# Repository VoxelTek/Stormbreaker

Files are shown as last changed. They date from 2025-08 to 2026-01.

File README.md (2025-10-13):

# Stormbreaker
### ~~A ripoff of YveltalGriffin's Mjolnir~~ 
### A companion board for [Thundervolt](https://github.com/mackieks/thundervolt)

Stormbreaker PCB front




## What is this?
Stormbreaker is a multifunction circuit board intended to be used alongside [Thundervolt](https://github.com/mackieks/thundervolt) in Wii portables. It handles battery charging and monitoring, power switching, storage interfacing, and a bit more. See the full list of features here.

## Why did I design this?
Thundervolt, while incredible, does not provide any battery management capability, nor does it provide any way for a user to toggle power to the system outside of disconnecting power from Thundervolt itself. As such, following the completion of Thundervolt, its creator YveltalGriffin began work on a companion board, named "Mjolnir". Mjolnir would handle everything from battery management to storage to fan control and more, and would integrate seamlessly with Thundervolt. However, development on Mjolnir has been temporarily halted, which pushed me to make a companion board myself. Hence, Stormbreaker was born.

## Where did the name come from?
In Norse mythology, Thor is the God of Thunder, and is often seen alongside his hammer, Mjolnir. In the Marvel Cinematic Universe, Thor lost Mjolnir, and instead forged an axe called Stormbreaker. 

As such, it seemed fitting to name this board, born from the absense of Mjolnir, "Stormbreaker".
###### Disclaimer: this board is not capable of summoning the Bifrost. PRs are welcome.

## What can this board do?
Functionality is largely split between the 4 ICs.
#### U1 - BQ25895
- Battery charging
  - Fast charging capability
  - Play-and-charge capability
- Battery voltage monitoring
  - Used to determine approximate remaining battery capacity (i.e. "percent")
- Shipping mode
#### U2 - GL835
- microSD to USB 2.0 adapter
- Supports hot-swaping microSD cards
#### U3 - ATtiny1616
- Initialises ICs
- Monitors system
  - Shuts off console in event of over-temp
  - Engages shipping mode when requested
  - Responds to errors from U1
- Powers on/off console after button press
  - Has safe shutdown capability
- Drives Neopixel LED (WS2812 or compatible)
- Controls fan speed using PWM
- Communicates with Wii over I2C
  - RVLoader fork allows various adjustments, including charge currents and charge voltage
#### U4 - HUSB238A
- PD sink controller
- Uses USB-C PD to request higher voltages (up to 12V) to allow for faster charging with lower current draw

GIF of rotating Stormbreaker PCB

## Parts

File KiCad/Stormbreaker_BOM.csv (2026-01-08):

Id | Designator | Footprint | Quantity | Designation | Supplier and ref
3 | C13 | C_0603_1608Metric | 1 | 0.1uF
5 | C5,C7,C6 | C_0402_1005Metric | 3 | 22uF
6 | U1 | Texas_RTW_WQFN-24-1EP_4x4mm_P0.5mm_EP2.7x2.7mm_ThermalVias | 1 | BQ25895RTW
7 | R9,R10,R11 | R_0402_1005Metric | 3 | 10k
8 | U3 | VQFN-20-1EP_3x3mm_P0.4mm_EP1.7x1.7mm | 1 | ATtiny1616-M
9 | C4,C9 | C_0402_1005Metric | 2 | 4.7uF
11 | L1 | L_PCMB053T | 1 | 3.3uH
15 | C12,C15,C8 | C_0402_1005Metric | 3 | 1μF
16 | R1 | R_0402_1005Metric | 1 | 260
17 | U2 | HVQFN-24-1EP_4x4mm_P0.5mm_EP2.5x2.5mm | 1 | ~
18 | C2,C1,C14,C16 | C_0603_1608Metric | 4 | 10uF
20 | J2 | USB_C_Receptacle_GCT_USB4105-xx-A_16P_TopMnt_Horizontal | 1 | USB_C_Receptacle_USB2.0_14P
21 | BT2 | JST_PH_B2B-PH-K_1x02_P2.00mm_Vertical | 1 | Battery_Cell
23 | Q2 | SOT-523 | 1 | NMOS
24 | Q1 | Vishay_PowerPAK_1212-8_Single | 1 | PMOS
25 | J1 | microSD_HC_Hirose_DM3D-SF | 1 | Micro_SD_Card_Det1
28 | SW1 | SW_TL3330AF260QG | 1 | SW_Push
29 | R2 | R_0402_1005Metric | 1 | 30.1k
30 | R7,R5 | R_0402_1005Metric | 2 | 1k
32 | R6 | R_0402_1005Metric | 1 | 900k
34 | R8 | R_0402_1005Metric | 1 | 100k
36 | R3 | R_0402_1005Metric | 1 | 5.23k
37 | U4 | QFN-16-1EP_3x3mm_P0.5mm_EP1.7x1.7mm_ThermalVias | 1 | HUSB238A
39 | C3 | C_0402_1005Metric | 1 | 47nF

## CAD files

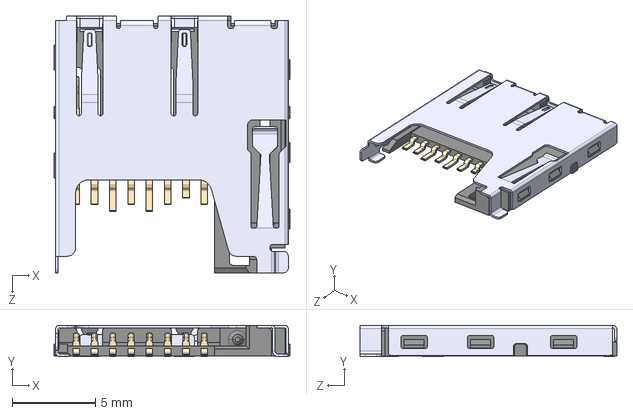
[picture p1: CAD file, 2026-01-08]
KiCad/3D/MEM2061-01-188-00-A.STEP
14.2 x 1.88 x 15.4 mm

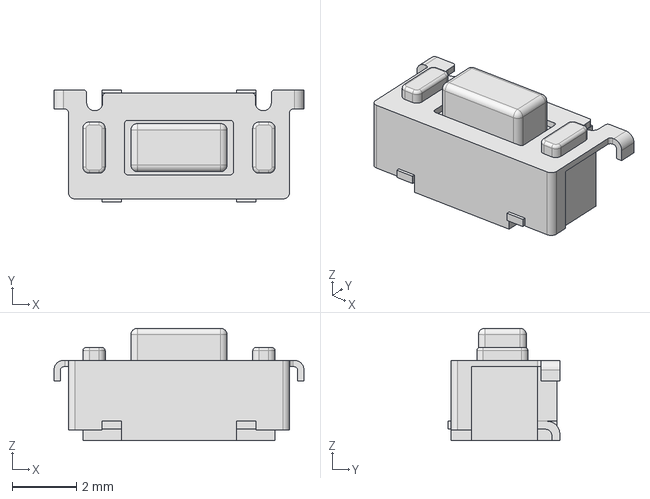
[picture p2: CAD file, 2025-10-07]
KiCad/3D/TL3330AFxxxQG.stp
7.80 x 3.50 x 3.51 mm

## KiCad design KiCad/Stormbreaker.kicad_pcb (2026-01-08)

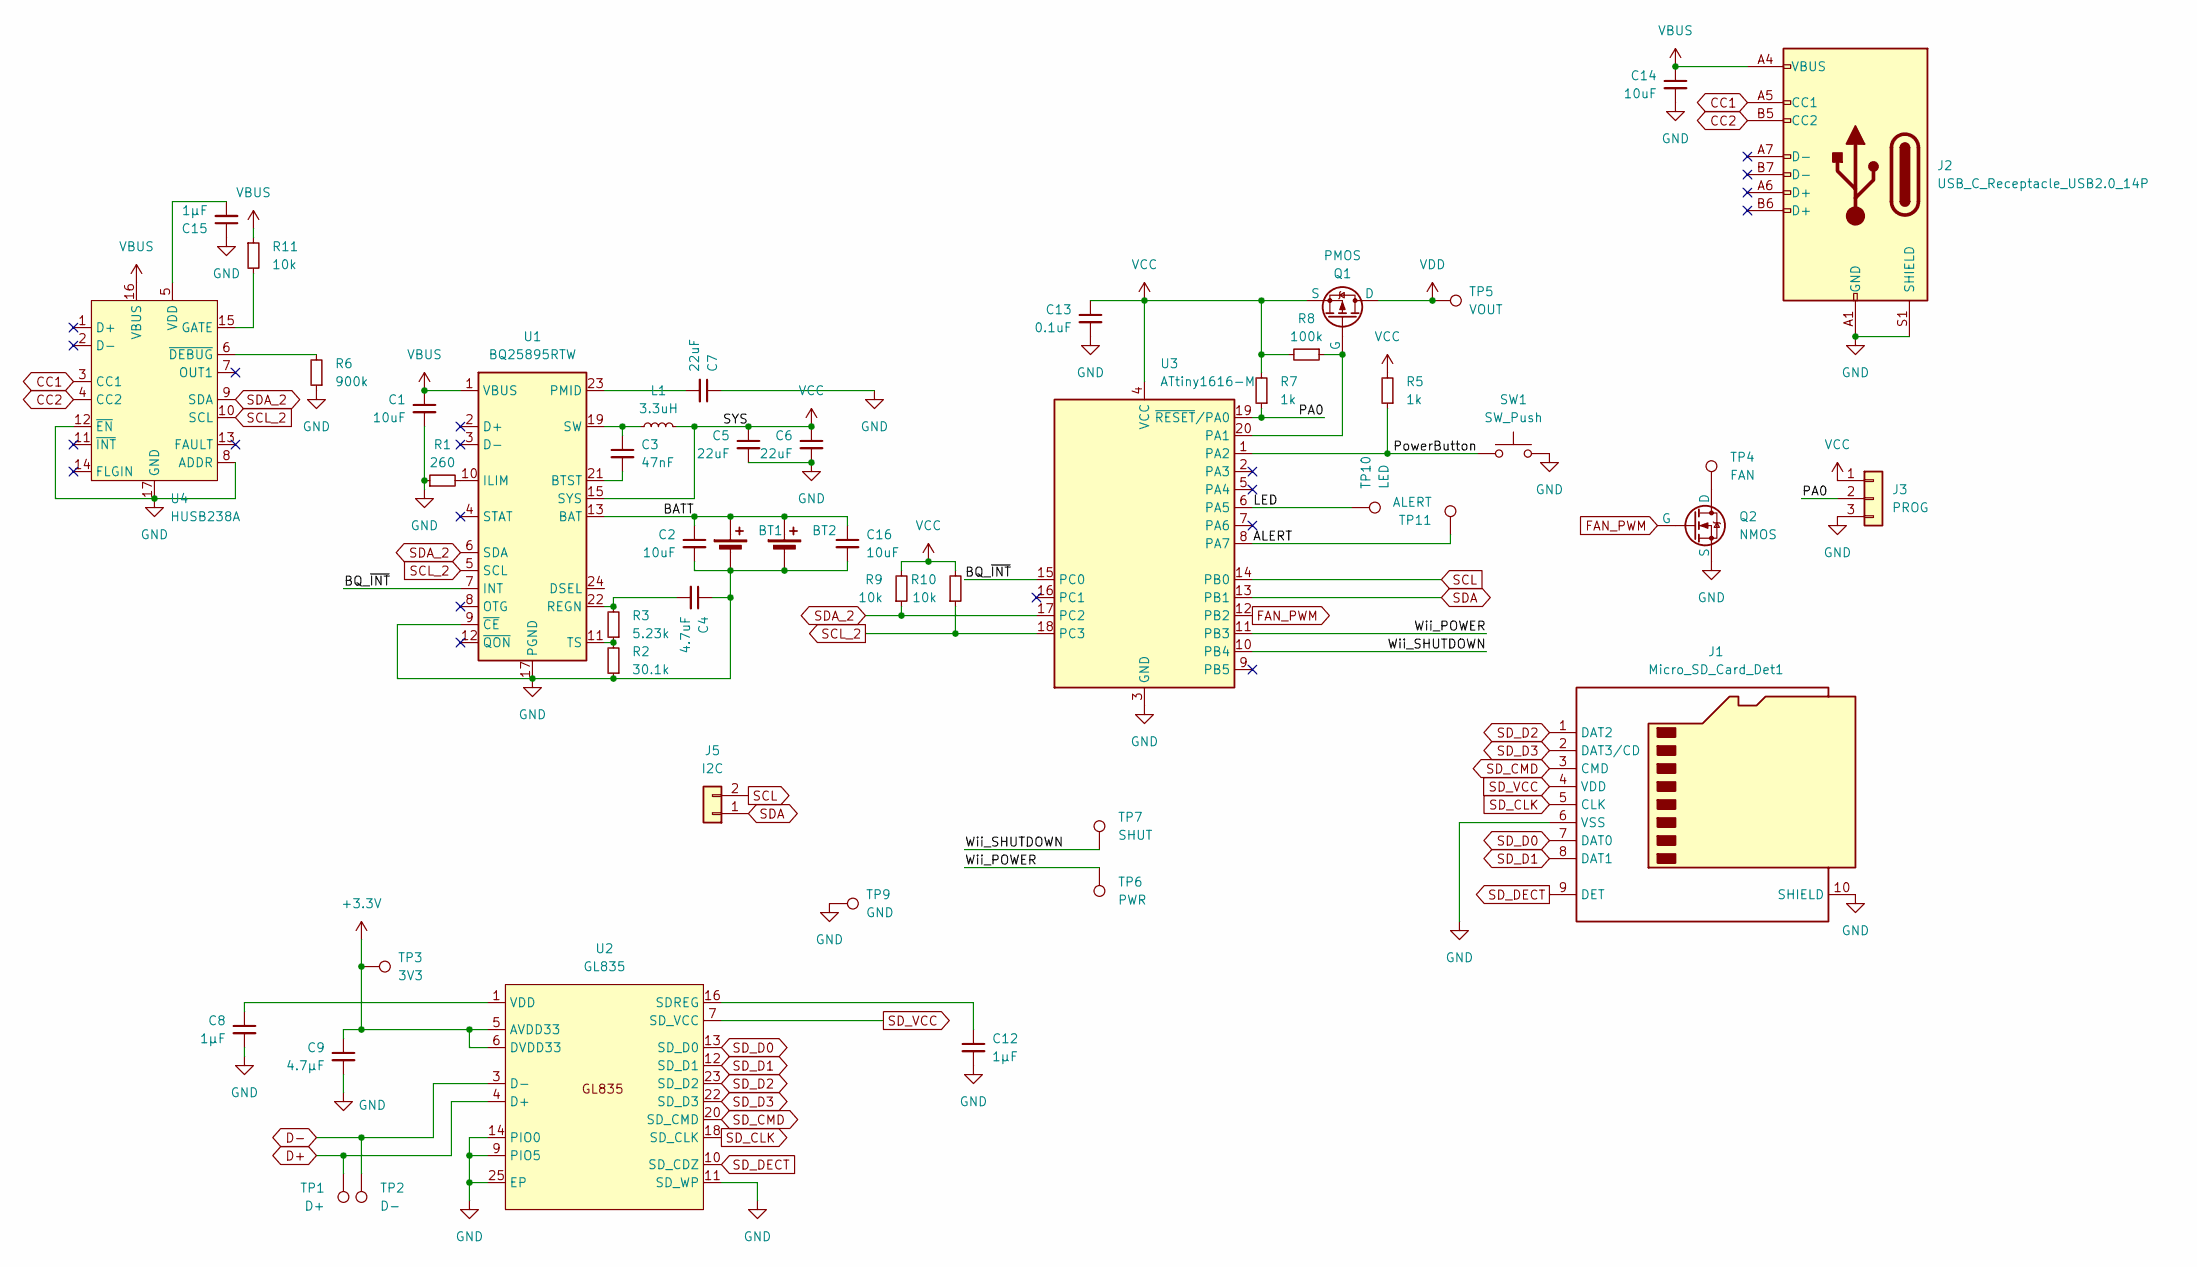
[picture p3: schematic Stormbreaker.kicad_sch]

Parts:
BT1: Battery_Cell; PinSocket_1x02_P1.27mm_Vertical
BT2: Battery_Cell; JST_PH_B2B-PH-K_1x02_P2.00mm_Vertical
C1, C2, C14, C16: 10uF; C_0603_1608Metric
C3: 47nF; C_0402_1005Metric
C4: 4.7uF; C_0402_1005Metric
C5, C6, C7: 22uF; C_0402_1005Metric
C8, C12, C15: 1μF; C_0402_1005Metric
C9: 4.7μF; C_0402_1005Metric
C13: 0.1uF; C_0603_1608Metric
J1: Micro_SD_Card_Det1; microSD_HC_Hirose_DM3D-SF
J2: USB_C_Receptacle_USB2.0_14P; USB_C_Receptacle_GCT_USB4105-xx-A_16P_TopMnt_Horizontal
J3: PROG; UPDI Pads
J5: I2C; PinSocket_1x02_P1.00mm_Vertical
L1: 3.3uH; L_PCMB053T
Q1: PMOS; Vishay_PowerPAK_1212-8_Single; Mouser au.mouser.com/ProductDetail/Vishay-Semi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
Q2: NMOS; SOT-523
R1: 260; R_0402_1005Metric
R2: 30.1k; R_0402_1005Metric
R3: 5.23k; R_0402_1005Metric
R5, R7: 1k; R_0402_1005Metric
R6: 900k; R_0402_1005Metric
R8: 100k; R_0402_1005Metric
R9, R10, R11: 10k; R_0402_1005Metric
SW1: SW_Push; SW_TL3330AF260QG
TP1: D+; TestPoint_Pad_D1.0mm_Small
TP2: D-; TestPoint_Pad_D1.0mm_Small
TP3: 3V3; TestPoint_Pad_D1.5mm
TP4: FAN; TestPoint_Pad_D1.0mm_Small
TP5: VOUT; TestPoint_Pad_D2.5mm
TP6: PWR; TestPoint_Pad_D1.0mm_Small
TP7: SHUT; TestPoint_Pad_D1.0mm_Small
TP9: GND; TestPoint_Pad_D2.5mm
TP10: LED; TestPoint_Pad_D1.0mm_Small
TP11: ALERT; TestPoint_Pad_D1.0mm_Small
U1: BQ25895RTW; Texas_RTW_WQFN-24-1EP_4x4mm_P0.5mm_EP2.7x2.7mm_ThermalVias
U2: GL835; HVQFN-24-1EP_4x4mm_P0.5mm_EP2.5x2.5mm
U3: ATtiny1616-M; VQFN-20-1EP_3x3mm_P0.4mm_EP1.7x1.7mm
U4: HUSB238A; QFN-16-1EP_3x3mm_P0.5mm_EP1.7x1.7mm_ThermalVias

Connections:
+3.3V: C9.1, TP3.1, U2.5 (AVDD33), U2.6 (DVDD33)
/ALERT: TP11.1, U3.8 (PA7)
/BATT: BT1.1 (+), BT2.1 (+), C2.1, C16.1, U1.13 (BAT), U1.14 (BAT)
/BQ_~INT: U1.7 (INT), U3.15 (PC0)
/LED: TP10.1, U3.6 (PA5)
/PA0: J3.2, R7.1, U3.19 (~RESET/PA0)
/PowerButton: R5.1, SW1.1, U3.1 (PA2)
/Wii_POWER: TP6.1, U3.11 (PB3)
/Wii_SHUTDOWN: TP7.1, U3.10 (PB4)
CC1: J2.A5 (CC1), U4.3 (CC1)
CC2: J2.B5 (CC2), U4.4 (CC2)
D+: TP1.1, U2.4 (D+)
D-: TP2.1, U2.3 (D-)
FAN_PWM: Q2.1 (G), U3.12 (PB2)
GND: BT1.2 (-), BT2.2 (-), C1.2, C2.2, C4.1, C5.2, C6.2, C7.1, C8.2, C9.2, C12.2, C13.2, C14.2, C15.1, C16.2, J1.6 (VSS), J1.10 (SHIELD), J1.11 (SHIELD), J2.A1 (GND), J2.A12 (GND), J2.B1 (GND), J2.B12 (GND), J2.S1 (SHIELD), J3.3, Q2.2 (S), R1.1, R2.1, R6.1, SW1.2, SW1.MP, TP9.1, U1.9 (~CE), U1.17 (PGND), U1.18 (PGND), U1.25 (PGND), U2.9 (PIO5), U2.11 (SD_WP), U2.14 (PIO0), U2.25 (EP), U3.3 (GND), U3.21 (GND), U4.8 (ADDR), U4.12 (~EN), U4.17 (GND)
unnamed: C3.1, L1.1, U1.19 (SW), U1.20 (SW)
unnamed: Q1.4 (G), R8.1, U3.20 (PA1)
unnamed: Q2.3 (D), TP4.1
unnamed: C3.2, U1.21 (BTST)
unnamed: R1.2, U1.10 (ILIM)
unnamed: C7.2, U1.23 (PMID)
unnamed: C4.2, R3.2, U1.22 (REGN)
unnamed: R2.2, R3.1, U1.11 (TS)
unnamed: C12.1, U2.16 (SDREG)
unnamed: C8.1, U2.1 (VDD)
unnamed: R11.2, U4.15 (GATE)
unnamed: C15.2, U4.5 (VDD)
unnamed: R6.2, U4.6 (~DEBUG)
SCL: J5.2, U3.14 (PB0)
SCL_2: R10.1, U1.5 (SCL), U3.18 (PC3), U4.10 (SCL)
SDA: J5.1, U3.13 (PB1)
SDA_2: R9.1, U1.6 (SDA), U3.17 (PC2), U4.9 (SDA)
SD_CLK: J1.5 (CLK), U2.18 (SD_CLK)
SD_CMD: J1.3 (CMD), U2.20 (SD_CMD)
SD_D0: J1.7 (DAT0), U2.13 (SD_D0)
SD_D1: J1.8 (DAT1), U2.12 (SD_D1)
SD_D2: J1.1 (DAT2), U2.23 (SD_D2)
SD_D3: J1.2 (DAT3/CD), U2.22 (SD_D3)
SD_DECT: J1.9 (DET), U2.10 (SD_CDZ)
SD_VCC: J1.4 (VDD), U2.7 (SD_VCC)
VBUS: C1.1, C14.1, J2.A4 (VBUS), J2.A9 (VBUS), J2.B4 (VBUS), J2.B9 (VBUS), R11.1, U1.1 (VBUS), U4.16 (VBUS)
VCC: C5.1, C6.1, C13.1, J3.1, L1.2, Q1.1 (S), Q1.2 (S), Q1.3 (S), R5.2, R7.2, R8.2, R9.2, R10.2, U1.15 (SYS), U1.16 (SYS), U3.4 (VCC); also elsewhere on the board
VDD: Q1.5 (D), TP5.1

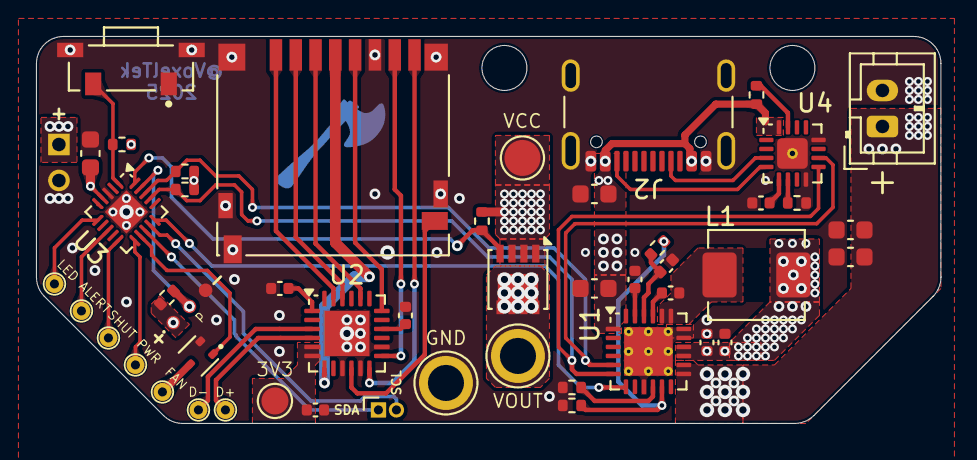
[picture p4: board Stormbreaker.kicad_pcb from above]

Board: 4 copper layers, 50.2 x 21.5 mm, 49 parts (0 on the bottom side), 43 nets.

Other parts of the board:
TP8: VCC; TestPoint_Pad_D2.0mm

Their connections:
VCC: TP8.1; also elsewhere on the board

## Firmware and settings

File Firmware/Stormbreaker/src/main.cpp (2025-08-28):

#include "main.h"

#include <avr/eeprom.h>
#include <avr/sleep.h>
#include <avr/interrupt.h>
#include <avr/io.h>
#include <avr/power.h>

#include <util/delay.h>

//#include <tinyNeoPixel.h>

#include "i2c_target.h"

#include "gpio.h"

#define STORM_I2C 0x50

#define ADDR_VER 0x00
#define ADDR_CHRGCURRENT 0x01
#define ADDR_PRECURRENT 0x02
#define ADDR_TERMCURRENT 0x03
#define ADDR_CHRGVOLTAGE 0x04
#define ADDR_FANSPEED 0x05

uint8_t ver = 0x01; // v0.1 (ver / 10)

//BBI2C bbi2c;

bool isPowered = false; // Is the Wii powered?
bool isCharging = false; // Is the BQ charging the batteries?

bool buttonTriggered = false; // Has the button been triggered?
bool triggeredSoftShutdown = false; // Did we trigger the soft shutdown?

bool isOverTemp = false;

uint8_t battCharge;
uint8_t battVolt = 0b1000101; //~3.7V
const uint8_t minBattVolt = 0b0010011; //~2.7V
uint8_t battVoltLevels[5] = {0b01011111, 0b1000101, 0b0100010, 0b0011000, 0b0010011}; // 4.2, 3.7, 3.0, 2.8, 2.7
uint8_t battChrgLevels[9] = {minBattVolt, 0x1c, 0x26, 0x30, 0x39, 0x43, 0x4c, 0x56, 0x5f};
uint8_t pwrErrorStatus = 0x00;
uint8_t chargeStatus = 0b00;
const uint8_t bqAddr = 0x6A;
uint8_t maxCurrent = 0x3F; // 3.25A
//byte chrgCurrent = 0b1000010; // 4224mA

/*
byte chrgCurrent = EEPROM.read(ADDR_CHRGCURRENT);
byte preCurrent = EEPROM.read(ADDR_PRECURRENT);
byte termCurrent = EEPROM.read(ADDR_TERMCURRENT);
byte chrgVoltage = EEPROM.read(ADDR_CHRGVOLTAGE);
*/

uint8_t chrgCurrent;
uint8_t preCurrent;
uint8_t termCurrent;
uint8_t chrgVoltage;
uint8_t fanSpeed;

const bool ilimEnabled = false;

//tinyNeoPixel pixels = tinyNeoPixel(NUMPIXELS, PIN_PA5, NEO_GRB);

/*
int I2CWriteRegister(BBI2C *pI2C, unsigned char iAddr, unsigned char reg, unsigned char value) {
    unsigned char buffer[2];
    buffer[0] = reg;   // Register address
    buffer[1] = value; // Data to write

    return I2CWrite(pI2C, iAddr, buffer, 2);
}
*/

void firstTimeCheck() {
  if (eeprom_read_byte(ADDR_VER) == 0) { // Check if there's no data in the EEPROM
    chrgCurrent = 0b1000010; // 4224mA
    preCurrent = 0b0001;
    termCurrent = 0b0011;
    chrgVoltage = 0b010111;
    fanSpeed = 0xFF;
    writeToEEPROM(); 
  }
  else {
    chrgCurrent = eeprom_read_byte(ADDR_CHRGCURRENT);
    preCurrent = eeprom_read_byte(ADDR_PRECURRENT);
    termCurrent = eeprom_read_byte(ADDR_TERMCURRENT);
    chrgVoltage = eeprom_read_byte(ADDR_CHRGVOLTAGE);
    fanSpeed = eeprom_read_byte(ADDR_FANSPEED);
  }
  eeprom_write_byte(ADDR_VER, ver);
}

int handle_register_read(uint8_t reg_addr, uint8_t *value) {
  /*
  if (numBytes == 0) return;

  byte reg = Wire.read();

  switch (reg) {
    case 0x00: // Get version
      requestedReg = &ver;
    break;

    case 0x02:
      applyChanges(); // Apply and store current settings
      isRequesting = false;
      Wire.read();
      return;
    break;

    case 0x04:
      requestedReg = &fanSpeed;
    break;

    case 0x0B:
      enableShipping(); // Don't need to bother doing anything, we'll be losing power soon anyway
      _delay_ms(1000);
    break;

    case 0x10:
      requestedReg = &chrgCurrent;
    break;

    case 0x11:
      requestedReg = &termCurrent;
    break;

    case 0x12:
      requestedReg = &preCurrent;
    break;

    case 0x13:
      requestedReg = &chrgVoltage;
    break;

    case 0x15:
      requestedReg = &chargeStatus;
    break;

    case 0x24:
      battChargeStatus();
      requestedReg = &battCharge;
    break;

    case 0x26:
      getBattVoltage();
      requestedReg = &battVolt;
    break;
  }

  if (!Wire.available()) {
    isRequesting = true;
    return;
  }
  else {
    isRequesting = false;
    *requestedReg = Wire.read();
  }
  */
}

int handle_register_write(uint8_t reg_addr, uint8_t value) {
  /*
  if (!isRequesting) {
    return;
  }
  Wire.write(*requestedReg);
  isRequesting = false;
  */
}

void setup() {
  //power_adc_disable(); // We don't need the ATtiny ADC, turn it off
  set_sleep_mode(SLEEP_MODE_PWR_DOWN); // Set sleep to low power mode
  sleep_enable(); // Enable sleeping, don't activate sleep yet though

  // Set unused pins to outputs
  /*
  pinMode(PIN_PA3, OUTPUT);
  pinMode(PIN_PA4, OUTPUT);
  pinMode(PIN_PA6, OUTPUT);
  pinMode(PIN_PB5, OUTPUT);
  pinMode(PIN_PC1, OUTPUT);
  */

  firstTimeCheck(); // Get settings from EEPROM

  //battChrgLevels = {chrgVoltage, 0x56, 0x4c, 0x43, 0x39, 0x30, 0x26, 0x1c};

  gpio_input(BUTTON);
  gpio_config(BUTTON, PORT_PULLUPEN_bm | PORT_ISC_FALLING_gc);

  gpio_input(CHRG_STAT);
  gpio_config(CHRG_STAT, PORT_ISC_BOTHEDGES_gc);

  gpio_input(TEMP_ALERT);
  gpio_config(TEMP_ALERT, PORT_PULLUPEN_bm | PORT_ISC_FALLING_gc);

  gpio_input(SOFT_SHUT);
  gpio_config(SOFT_SHUT, PORT_ISC_RISING_gc);

  gpio_output(SOFT_PWR);
  gpio_set_low(SOFT_PWR);

  gpio_output(FAN);
  //gpio_config(FAN, 0);
  gpio_set_low(FAN);


  gpio_output(PWR_ON);
  gpio_set_high(PWR_ON); // Makes sure console is off

  /*
  attachInterrupt(digitalPinToInterrupt(BUTTON), powerButton, LOW);
  attachInterrupt(digitalPinToInterrupt(SOFT_SHUT), softShutdown, RISING);
  attachInterrupt(digitalPinToInterrupt(CHRG_STAT), chargingStatus, CHANGE);
  attachInterrupt(digitalPinToInterrupt(TEMP_ALERT), overTemp, LOW);
  */
  
  setFan(false); // Turn off fan

  /*
  memset(&bbi2c, 0, sizeof(bbi2c));
  bbi2c.bWire = false;
  bbi2c.iSDA = SDA2;
  bbi2c.iSCL = SCL2;
  I2CInit(&bbi2c, 0xFFFF);
  

  Wire.onReceive(receiveDataWire);
  Wire.onRequest(transmitDataWire);
  Wire.begin(STORM_I2C);
  */

  i2c_target_init(STORM_I2C, handle_register_read, handle_register_write);

  //pixels.begin();

  setupBQ();
}

void loop() {
  if (isPowered) {
    monitorBatt();
    _delay_ms(500);
  }
  else if (isCharging) {
    chargingStatus();
    _delay_ms(500);
  }
  else {
    sleep_cpu(); // The console isn't on, nor is it charging. Enter sleep to save power.
  }
}

void overTemp() {
  triggerShutdown(); // Trigger shutdown process
  //analogWrite(FAN, 0xff); // fan at max speed, keep console cool
  powerLED(5);
  isOverTemp = true;
  for (int i = 0; i < 120; i++) { // 2 min to cool down
    _delay_ms(1000);
  }
  isOverTemp = false;
  setFan(false); // disable cooling fan
}

void powerButton() { // Power button has been pressed
  if (!buttonTriggered && gpio_read(BUTTON) == false) {
    buttonTriggered = true; // Make sure other instances of this function don't run. They shouldn't, hopefully, but eh.
    _delay_ms(1000); // Wait in order to prevent bouncing and accidental presses
    if (gpio_read(BUTTON) == false) {
      if (isPowered) {
        triggerShutdown(); // Is it on? Turn it off.
      }
      else {
        getBattVoltage();
        if (((battVolt > minBattVolt) || isCharging) && !isOverTemp && (pwrErrorStatus == 0x00)) { 
        // Check that either the battery is charged enough, or console is charging, 
        // AND make sure there's no over-temp issues
        // AND make sure there's no power errors
          consoleOn(); // Voltage is high enough or currently charging, turn on console
        }
        else {
          powerLED(5); // Flash red light, battery too low OR over temp
        }
      }
    }
    while (gpio_read(BUTTON) == false) { // Wait for button to stop being pressed
      _delay_ms(100);
    }
    _delay_ms(250); // Debounce protection...kinda
    buttonTriggered = false;
  }
}

void triggerShutdown() {
  if (!triggeredSoftShutdown && isPowered) {
    gpio_set_high(SOFT_PWR); // Trigger the soft shutdown sequence on the Wii
    _delay_ms(30);
    gpio_set_low(SOFT_PWR);
    triggeredSoftShutdown = true;
    _delay_ms(2500);
    if (isPowered && triggeredSoftShutdown) { // Wii did not shut itself down safely, timeout and force a power-off
      consoleOff();
      triggeredSoftShutdown = false;
    }
  }
  else if (!isPowered) {
    consoleOff(); // If some bug happens, and the console is on while this thinks it isn't, might as well make sure it's shut down.
  }
}

void softShutdown() {
  if (gpio_read(SOFT_SHUT) == true) { // Check that the pin is actually high
    _delay_ms(100);
    consoleOff();
    triggeredSoftShutdown = false;
  }
}

void chargingStatus() {
  unsigned char chrgStat = 0x00;
  //I2CReadRegister(&bbi2c, bqAddr, 0x0B, &chrgStat, 0x8);
  chargeStatus = ((chrgStat & 0b00011000) >> 3);

  unsigned char errorStat = 0x00;
  //I2CReadRegister(&bbi2c, bqAddr, 0x0C, &errorStat, 0x8);
  pwrErrorStatus = errorStat;
  if (pwrErrorStatus != 0x00) { // Uh oh, *something* is wrong
    triggerShutdown();
    if (pwrErrorStatus & (1 << 5)) { // oh jeez stuff is hot this is really bad
      overTemp();
      return;
    }
    else if (pwrErrorStatus & (1 << 3)) { // ???? the battery is TOO charged????
      enableShipping();
    }
  }

  if (chargeStatus == 0b00) {
    isCharging = false;
    if (isPowered) {
      monitorBatt();
    }
    else {
      powerLED(0); // Not on, not charging

    }
  }
  else {
    isCharging = true;
    if (chargeStatus == 0b11) { // Finished charging
      powerLED(7);
    }
    else {
      powerLED(6); // Charging, not complete
    }
  }
  _delay_ms(100);
}

void setFan(bool active) {
  if (active) {
    //analogWrite(FAN, fanSpeed);
  }
  else {
    gpio_set_low(FAN);
  }
}


void powerLED(uint8_t mode) {
  /*
  0 = All LEDs off
  1 = Full charge -- Green
  2 = Medium charge -- Yellow
  3 = Low charge -- Orange
  4 = About to run out -- Red
  5 = Low-power shutdown, or other error -- Couple red flashes
  6 = Charging -- Soft blue
  7 = Charging, full -- Soft pink
  */
  switch (mode) {
    case 0:
      setLED(0, 0, 0, 0, false);
    break;

    case 1:
      setLED(0, 255, 0, 128, true); // Green
    break;

    case 2:
      setLED(255, 255, 0, 128, true); // Yellow
    break;

    case 3:
      setLED(255, 128, 0, 128, true); // Orange
    break;

    case 4:
      setLED(255, 0, 0, 128, true); // Red
    break;

    case 5:
      for (int i = 0; i < 5; i++) { // Flash red
        setLED(255, 0, 0, 128, true);
        _delay_ms(100);
        setLED(0, 0, 0, 0, false);
        _delay_ms(100);
      }
      powerLED(0);
    break;

    case 6:
      setLED(0, 0, 255, 64, true); // Dim blue
    break;

    case 7:
      setLED(255, 183, 197, 64, true); // Dim sakura pink
    break;

    default:
      powerLED(0); // off
    break;
  }
}

void consoleOn() {
  /*REG02*/
  unsigned char reg02 = (0b11111100); // Disable D+/D- detection and such
  // Continuous battery voltage reading if console is on
  //I2CWriteRegister(&bbi2c, bqAddr, 0x02, reg02);

  gpio_set_low(PWR_ON); // Activate MOSFET
  isPowered = true;

  setFan(true); // Enable fan,

  monitorBatt();
}

void consoleOff() {
  /*REG02*/
  unsigned char reg02 = (0b00111100); // Disable D+/D- detection and such
  // Disable continuous battery voltage reading
  //I2CWriteRegister(&bbi2c, bqAddr, 0x02, reg02);

  gpio_set_high(PWR_ON); // Deactivate MOSFET
  isPowered = false;

  setFan(false);

  monitorBatt();
}

void enableShipping() {
  /*REG09*/
  unsigned char reg09 = (1 << 5); // Enable shipping mode
  //I2CWriteRegister(&bbi2c, bqAddr, 0x09, reg09);
}

void setupBQ() {
  /*REG00*/
  unsigned char reg00 = ((maxCurrent) | (ilimEnabled << 6)); // Set max current and ILIM.
  //I2CWriteRegister(&bbi2c, bqAddr, 0x00, reg00);

  /*REG02*/
  unsigned char reg02 = (0b00111100); // Disable D+/D- detection and such
  if (isPowered){
    reg02 |= 0b11000000; // Continuous battery voltage reading if console is on
  }
  //I2CWriteRegister(&bbi2c, bqAddr, 0x02, reg02);

  /*REG03*/
  unsigned char reg03 = (0b00011010); // Disable OTG
  //I2CWriteRegister(&bbi2c, bqAddr, 0x03, reg03);

  /*REG04*/
  unsigned char reg04 = (0x00 | chrgCurrent); // Set fast charge current
  //I2CWriteRegister(&bbi2c, bqAddr, 0x04, reg04);

  /*REG05*/
  unsigned char reg05 = ((preCurrent << 4) | (0b1111 & termCurrent)); // Set term charge current
  //I2CWriteRegister(&bbi2c, bqAddr, 0x05, reg05);

  /*REG06*/
  unsigned char reg06 = (0b00000011 | (chrgVoltage << 2)); // Set max battery voltage
  //I2CWriteRegister(&bbi2c, bqAddr, 0x06, reg06);
}

void writeToEEPROM() {
  eeprom_write_byte(ADDR_CHRGCURRENT, chrgCurrent);
  eeprom_write_byte(ADDR_PRECURRENT, preCurrent);
  eeprom_write_byte(ADDR_TERMCURRENT, termCurrent);
  eeprom_write_byte(ADDR_CHRGVOLTAGE, chrgVoltage);
  eeprom_write_byte(ADDR_FANSPEED, fanSpeed);
}

void applyChanges() {
  writeToEEPROM();
  setFan(isPowered);
  setupBQ();
}


void getBattVoltage() {
  if (!isPowered) {
    unsigned char reg02 = (0b10111100); // Disable D+/D- detection and such
    // Get single voltage reading
    //I2CWriteRegister(&bbi2c, bqAddr, 0x02, reg02);
    _delay_ms(200);
  }
  unsigned char adcRegStatus = 0;
  //I2CReadRegister(&bbi2c, bqAddr, 0x0E, &adcRegStatus, 0x8);
  adcRegStatus &= 0b1111111;
  battVolt = adcRegStatus;
}


void setLED(uint8_t r, uint8_t g, uint8_t b, uint8_t bright, bool enabled) {
  if (!enabled) {
    //pixels.clear();
  }
  else {
    for (int i = 0; i < NUMPIXELS; i++) {

      // pixels.Color takes RGB values, from 0,0,0 up to 255,255,255
      //pixels.setPixelColor(i, pixels.Color(r, g, b));
      //pixels.setBrightness(bright);

      //pixels.show(); // This sends the updated pixel color to the hardware.

      _delay_ms(50); // Delay for a period of time (in milliseconds).

    }
  }
}

void battChargeStatus() {
  if (chargeStatus == 0b11) {
    battCharge = 0xff;
    return;
  }
  getBattVoltage();
  _delay_ms(100);
  
  float tmp;

  for (int i = 0; i < 8; i++) {
    if ((battVolt >= battChrgLevels[i]) && (battVolt < battChrgLevels[i+1])) {
      tmp = i + ((battVolt - battChrgLevels[i])/ (battChrgLevels[i+1] - battChrgLevels[i]));
      tmp *= 0x20;
      battCharge = int(tmp);
      return;
    }
  }
}

void monitorBatt() {
  getBattVoltage();
  _delay_ms(100);
  if (isCharging || !isPowered) { 
    // If not turned on, or if charging, let the chargingStatus function handle it
    powerLED(0);
    chargingStatus();
    return;
  }
  if (battVolt < minBattVolt) {
    triggerShutdown(); // Battery too low, emergency shutdown
    powerLED(5); // Show flashing red for error
    return;
  }
  if ((battVolt <= battVoltLevels[0]) && (battVolt > battVoltLevels[1])) {
    powerLED(1); // High charge
  }
  else if ((battVolt <= battVoltLevels[1]) && (battVolt > battVoltLevels[2])) {
    powerLED(2); // Medium charge
  }
  else if ((battVolt <= battVoltLevels[2]) && (battVolt > battVoltLevels[3])) {
    powerLED(3); // Low charge
  }
  else if ((battVolt <= battVoltLevels[3]) && (battVolt > battVoltLevels[4])) {
    powerLED(4); // ABOUT TO RUN OUT
  }
}

int main() {
  setup();
  while (1) {
    loop();
  }
  return 1;
}

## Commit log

2025-05-22 Switch to larger inductor
    [Stormbreaker.kicad_pcb, Stormbreaker.kicad_sch]
2025-08-15 Switch to different button
    Something's up with KiCad, not sure why.
    [Stormbreaker.kicad_pcb, Stormbreaker.kicad_sch]
2025-08-28 WIP -- Move to PlatformIO
    [Stormbreaker.kicad_pcb]
2025-09-02 Nearing completion of firmware rewrite
    [Stormbreaker.kicad_pcb, Stormbreaker.kicad_sch]
2025-09-04 Add ADC functions, PWM fan control to come
2025-09-04 Several misc PCB improvements
    [Stormbreaker.kicad_pcb]
2025-09-07 Fix I2C communication between RVLoader and Storm
    [main.c]
2025-09-08 Remove original `.ino`, implement fan PWM, misc
    [Stormbreaker.kicad_sch]
2025-10-06 Misc board improvements
    [Stormbreaker.kicad_pcb, Stormbreaker.kicad_sch]
2025-10-07 v3 hardware design: largely complete
    [Stormbreaker.kicad_pcb, Stormbreaker.kicad_sch, TL3330AFxxxQG.stp]
2025-10-07 Rework of some things
    TODO:
    - Fix I2C functions
    - Add HUSB238A setup code
    [main.c]
2025-10-07 Improve and simplify I2C code
2025-10-08 Nearing completion of revision 3
    [Stormbreaker.kicad_pcb]
2025-10-08 Add fancy logo
    [Stormbreaker.kicad_pcb]
2025-10-08 Misc changes, README.md update
    [Stormbreaker.kicad_pcb, Stormbreaker.kicad_sch]
2025-10-09 Minor hardware changes
    [Stormbreaker.kicad_pcb]
2025-10-09 Update README.md
    Replace main image, add animated GIF of spinning board
2025-10-10 Fix 3D model, other misc changes
    [Stormbreaker.kicad_pcb]
2025-12-27 Minor changes, regenerate gerbers
    [Stormbreaker-B_Cu.gbr, Stormbreaker-B_Mask.gbr, Stormbreaker-B_Paste.gbr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]
2026-01-08 Add alternate microSD slot
    [MEM2061-01-188-00-A.STEP]
2026-01-08 Edit BOM, compress gerbers, fix doxygen
    [Stormbreaker_BOM.csv]
2026-01-08 Generate ibom, add value for GL835
    [Stormbreaker.kicad_pcb, Stormbreaker.kicad_sch]
